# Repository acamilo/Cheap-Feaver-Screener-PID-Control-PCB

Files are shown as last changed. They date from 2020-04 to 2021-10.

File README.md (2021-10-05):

# Cheap-Feaver-Screener-PID-Control-PCB
PCB to control two heating elements wit i2c temp sensors.

Demo Video of version 1 that used a Ceramic Resistor

IMAGE ALT TEXT HERE (https://youtu.be/IRxbQEMiYrg?t=2844)

Demo Video of version 2 that used a PC trace.

IMAGE ALT TEXT HERE (https://youtu.be/efQGo4ABkNo?t=1757)

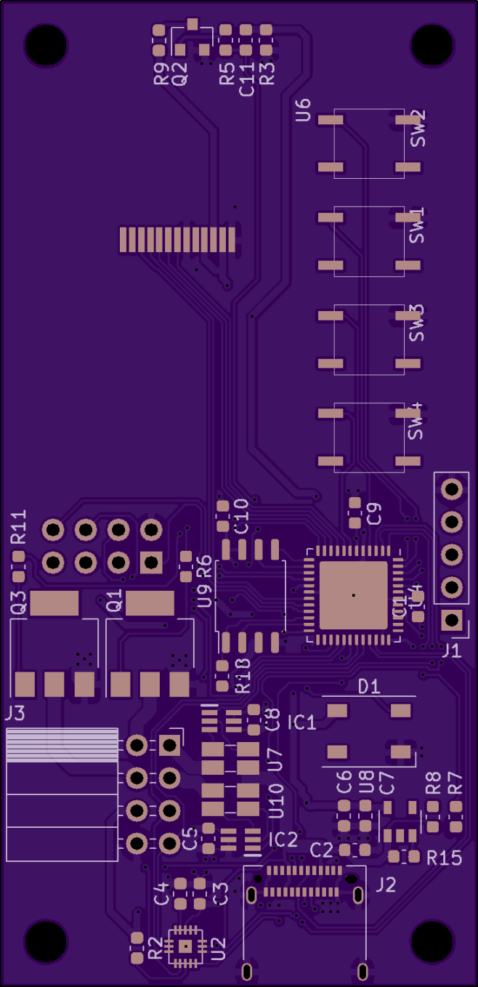
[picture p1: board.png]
Image of board


# Features
 * USB-C with PD controller to request more power from chargers and battery packs.
 * Two heating element drivers that can drive 3A each.
 * Interfaces with external i2c or Dallas temp sensors.
 * 240x135 TFT display ad 4 buttons for a user interface.
 * Slot for an optional esp8266-01 module for wireless connectivity. (Status, MQTT updates, etc..)
 * Neopixel for indicating status

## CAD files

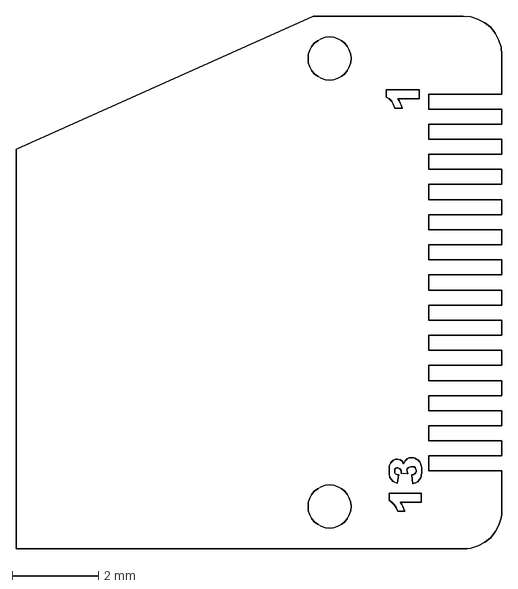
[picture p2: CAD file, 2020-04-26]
tft-240x135-cable.dxf
11.3 x 12.4 mm

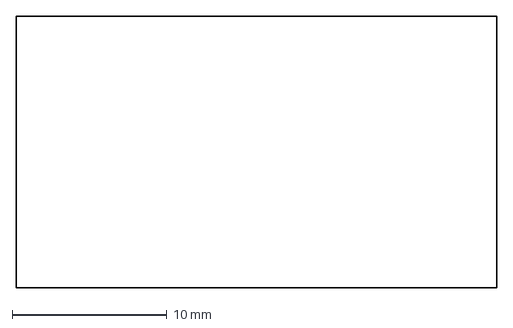
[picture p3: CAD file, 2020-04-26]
tft-240x135-footprint.dxf
31.0 x 17.6 mm

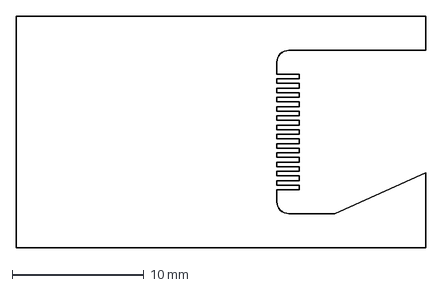
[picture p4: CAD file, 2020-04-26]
tft-240x135-footprint-cutout.dxf
31.0 x 17.6 mm

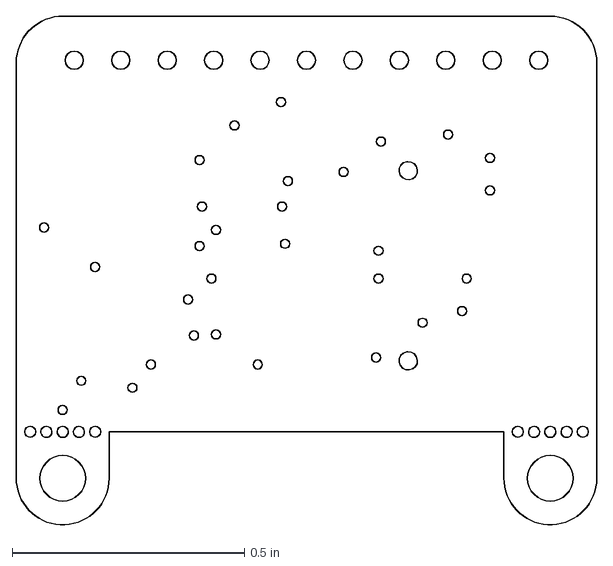
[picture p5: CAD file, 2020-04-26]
TFT-240x135.dxf
1.25 x 1.10 in

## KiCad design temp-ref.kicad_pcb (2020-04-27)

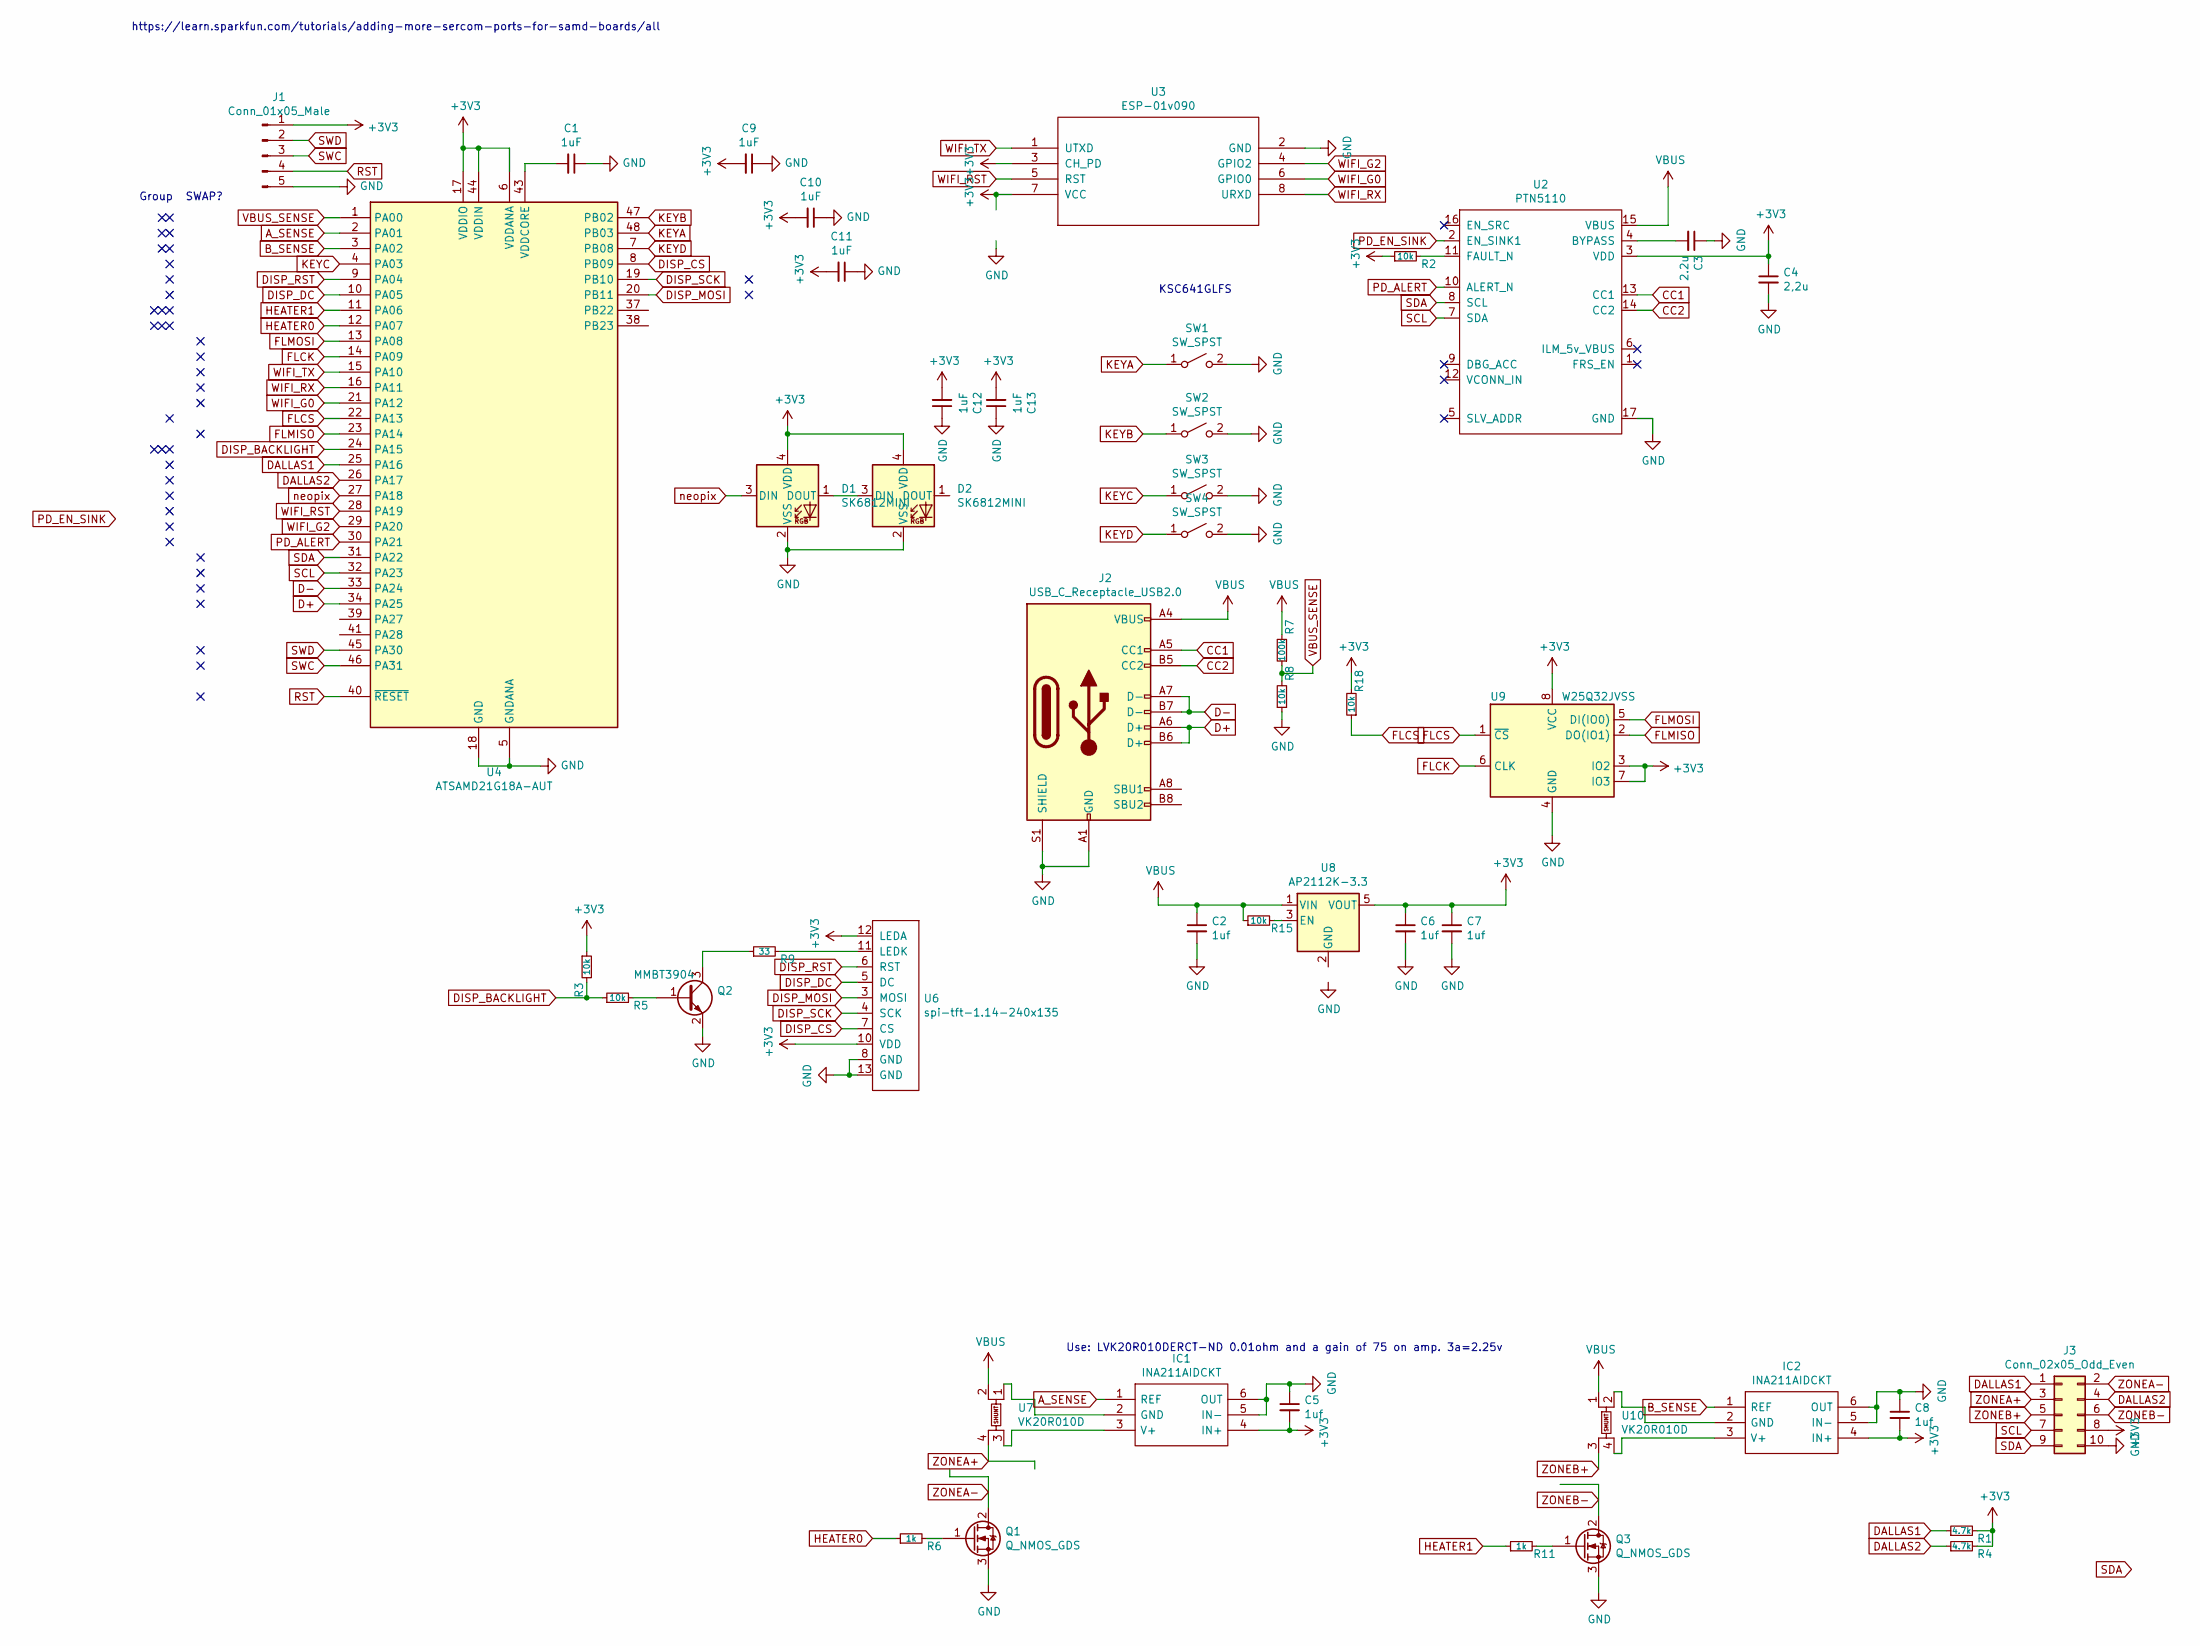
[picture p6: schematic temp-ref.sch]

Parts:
C1, C9, C10, C11, C12, C13: 1uF; C_0603_1608Metric
C2, C5, C6, C7, C8: 1uf; C_0603_1608Metric
C3: 2.2u; C_0603_1608Metric
C4: 2,2u; C_0603_1608Metric
D1, D2: SK6812MINI; LED_SK6812MINI_PLCC4_3.5x3.5mm_P1.75mm
IC1, IC2: INA211AIDCKT; SOT65P210X110-6N; Manufacturer_Part_Number INA211AIDCKT; Mouser Part Number 595-INA211AIDCKT
J1: Conn_01x05_Male; PinHeader_1x05_P2.54mm_Vertical
J2: USB_C_Receptacle_USB2.0; USB_C_Receptacle_Amphenol_12401610E4-2A
J3: Conn_02x05_Odd_Even; PinSocket_2x05_P2.54mm_Horizontal
Q1, Q3: Q_NMOS_GDS; SOT-223
Q2: MMBT3904; SOT-23
R1, R4: 4.7k; R_0603_1608Metric
R2, R3, R5, R8, R15, R18: 10k; R_0603_1608Metric
R6, R11: 1k; R_0603_1608Metric
R7: 100k; R_0603_1608Metric
R9: 33; R_0603_1608Metric
SW1, SW2, SW3, SW4: SW_SPST; 5.2mm_Tact_reverse_mount
U2: PTN5110; HX2QFN16
U3: ESP-01v090; ESP-01
U4: ATSAMD21G18A-AUT; QFN-48-1EP_7x7mm_P0.5mm_EP5.3x5.3mm
U6: spi-tft-1.14-240x135; TFT-1.14-240-135
U7, U10: VK20R010D; R_Shunt_Ohmite_LVK12
U8: AP2112K-3.3; SOT-23-5
U9: W25Q32JVSS; SOIC-8_5.23x5.23mm_P1.27mm

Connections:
+3V3: C4.1, C5.2, C6.1, C7.1, C8.2, C9.2, C10.2, C11.2, C12.2, C13.2, D1.4 (VDD), D2.4 (VDD), IC1.4 (IN+), IC2.4 (IN+), J1.1, J3.8, R1.2, R2.1, R3.1, R4.2, R18.2, U2.3 (VDD), U3.3 (CH_PD), U3.7 (VCC), U4.6 (VDDANA), U4.17 (VDDIO), U4.36 (VDDIO), U4.44 (VDDIN), U6.10 (VDD), U6.12 (LEDA), U8.5 (VOUT), U9.3 (IO2), U9.7 (IO3), U9.8 (VCC)
A_SENSE: IC1.1 (REF), U4.2 (PA01)
B_SENSE: IC2.1 (REF), U4.3 (PA02)
CC1: J2.A5 (CC1), U2.13 (CC1)
CC2: J2.B5 (CC2), U2.14 (CC2)
D+: J2.A6 (D+), J2.B6 (D+), U4.34 (PA25)
D-: J2.A7 (D-), J2.B7 (D-), U4.33 (PA24)
DALLAS1: J3.1, R1.1, U4.25 (PA16)
DALLAS2: J3.4, R4.1, U4.26 (PA17)
DISP_BACKLIGHT: R3.2, R5.1, U4.24 (PA15)
DISP_CS: U4.8 (PB09), U6.7 (CS)
DISP_DC: U4.10 (PA05), U6.5 (DC)
DISP_MOSI: U4.20 (PB11), U6.3 (MOSI)
DISP_RST: U4.9 (PA04), U6.6 (RST)
DISP_SCK: U4.19 (PB10), U6.4 (SCK)
FLCK: U4.14 (PA09), U9.6 (CLK)
FLCS: R18.1, U4.22 (PA13), U9.1 (~CS)
FLMISO: U4.23 (PA14), U9.2 (DO(IO1))
FLMOSI: U4.13 (PA08), U9.5 (DI(IO0))
GND: C1.1, C2.2, C3.1, C4.2, C5.1, C6.2, C7.2, C8.1, C9.1, C10.1, C11.1, C12.1, C13.1, D1.2 (VSS), D2.2 (VSS), IC1.5 (IN-), IC1.6 (OUT), IC2.5 (IN-), IC2.6 (OUT), J1.5, J2.A1 (GND), J2.A12 (GND), J2.B1 (GND), J2.B12 (GND), J2.S1 (SHIELD), J3.10, Q1.3 (S), Q2.2 (E), Q3.3 (S), R8.1, SW1.2 (B), SW2.2 (B), SW3.2 (B), SW4.2 (B), U2.17 (GND), U3.2 (GND), U4.5 (GNDANA), U4.18 (GND), U4.35 (GND), U4.42 (GND), U4.49, U6.8 (GND), U6.13 (GND), U9.4 (GND)
HEATER0: R6.1, U4.12 (PA07)
HEATER1: R11.1, U4.11 (PA06)
KEYA: SW1.1 (A), U4.48 (PB03)
KEYB: SW2.1 (A), U4.47 (PB02)
KEYC: SW3.1 (A), U4.4 (PA03)
KEYD: SW4.1 (A), U4.7 (PB08)
unnamed: C1.2, U4.43 (VDDCORE)
unnamed: C3.2, U2.4 (BYPASS)
unnamed: D1.1 (DOUT), D2.3 (DIN)
unnamed: IC1.2 (GND), U7.1
unnamed: IC1.3 (V+), U7.3
unnamed: IC2.2 (GND), U10.2
unnamed: IC2.3 (V+), U10.4
unnamed: Q1.1 (G), R6.2
unnamed: Q2.1 (B), R5.2
unnamed: Q2.3 (C), R9.1
unnamed: Q3.1 (G), R11.2
unnamed: R2.2, U2.11 (FAULT_N)
unnamed: R9.2, U6.11 (LEDK)
unnamed: R15.2, U8.3 (EN)
PD_ALERT: U2.10 (ALERT_N), U4.30 (PA21)
PD_EN_SINK: U2.2 (EN_SINK1)
RST: J1.4, U4.40 (~RESET)
SCL: J3.7, U2.7 (SDA), U4.32 (PA23)
SDA: J3.9, U2.8 (SCL), U4.31 (PA22)
SWC: J1.3, U4.46 (PA31)
SWD: J1.2, U4.45 (PA30)
VBUS: C2.1, J2.A4 (VBUS), J2.A9 (VBUS), J2.B4 (VBUS), J2.B9 (VBUS), R7.2, R15.1, U2.15 (VBUS), U7.2, U8.1 (VIN), U10.1
VBUS_SENSE: R7.1, R8.2, U4.1 (PA00)
WIFI_G0: U3.6 (GPIO0), U4.21 (PA12)
WIFI_G2: U3.4 (GPIO2), U4.29 (PA20)
WIFI_RST: U3.5 (RST), U4.28 (PA19)
WIFI_RX: U3.8 (URXD), U4.16 (PA11)
WIFI_TX: U3.1 (UTXD), U4.15 (PA10)
ZONEA+: J3.3, U7.4
ZONEA-: J3.2, Q1.2 (D)
ZONEB+: J3.5, U10.3
ZONEB-: J3.6, Q3.2 (D)
neopix: D1.3 (DIN), U4.27 (PA18)

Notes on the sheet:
KSC641GLFS
Use: LVK20R010DERCT-ND 0.01ohm and a gain of 75 on amp. 3a=2.25v
https://learn.sparkfun.com/tutorials/adding-more-sercom-ports-for-samd-boards/all
SWAP?
Group

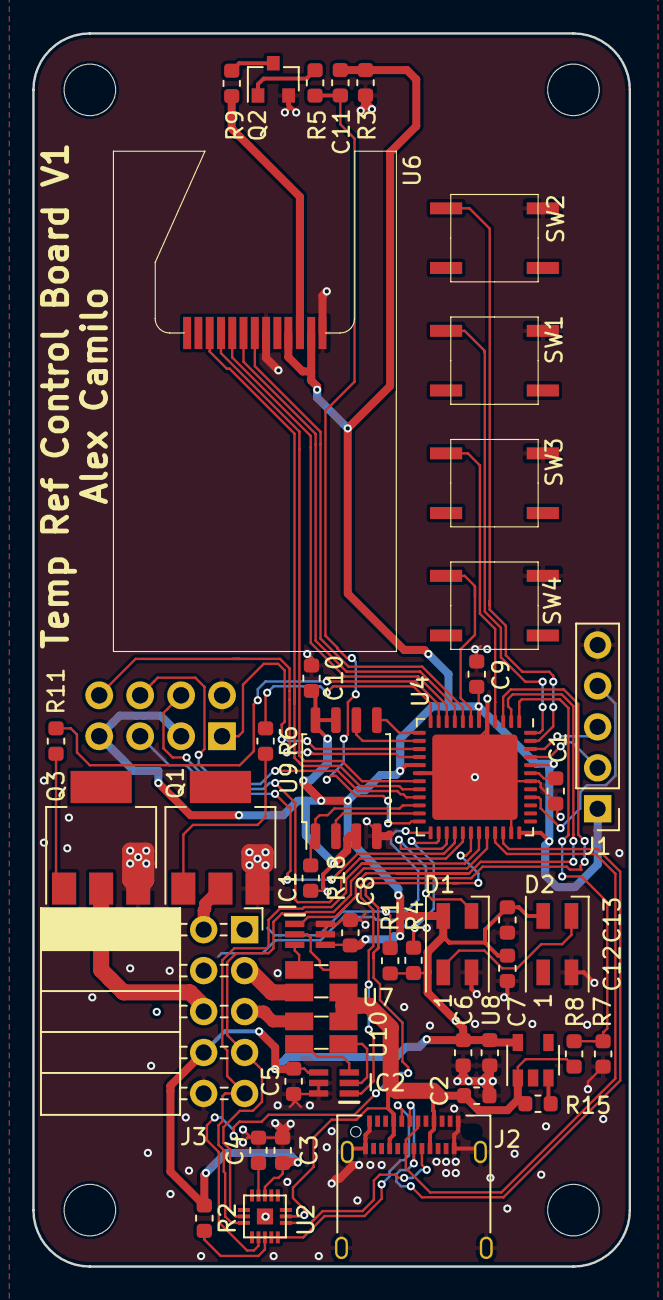
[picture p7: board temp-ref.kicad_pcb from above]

Board: 2 copper layers, 37.0 x 76.5 mm, 47 parts (1 on the bottom side), 58 nets.

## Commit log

2020-04-25 Committing progress
    [temp-ref.kicad_pcb, temp-ref.sch]
2020-04-26 Added kicad gitignore
2020-04-26 layout attempt 1
    [TFT-240x135.dxf, temp-ref.kicad_pcb, temp-ref.sch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]
2020-04-26 REworked electronics into smaller board. Heating elements will be seperate.
    [noname.kicad_pcb, temp-ref.kicad_pcb, temp-ref.sch]
2020-04-26 Update temp-ref.kicad_pcb
    removed errant via
    [temp-ref.kicad_pcb]
2020-04-27 3d models added, Added dallas pins, added nepixels, moved some elements around.
    [temp-ref.kicad_pcb, temp-ref.sch]
2020-04-27 Make cable outline visible on silk
    [temp-ref.kicad_pcb]
